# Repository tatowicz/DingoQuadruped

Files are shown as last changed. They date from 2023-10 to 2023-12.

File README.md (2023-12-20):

# Dingo Quadruped

<p align="center">
    
</p>

## Overview
This repository hosts the code for the Dingo Quadruped, a robot designed to be low-cost but capable of conducting research and being extensively modified with additional actuators and sensors. CAD for the Dingo can be found [here](https://grabcad.com/library/dingo-robot-quadruped-2). A full Bill of materials for purchasable components can be found within this repo.

This code is based on the [Stanford Pupper](https://github.com/stanfordroboticsclub/StanfordQuadruped) and [notspot](https://github.com/lnotspotl/notspot_sim_py) codebases, with extensive modifications, including integration into ROS 1 Noetic.

The repository includes a driver node, dingo_driver.py, which should be used anytime the code is run. This file enables joystick control of the Dingo, and allows joint and/or task space commands generated by any other code to be passed through the driver via the appropriate ROS command topics. The joystick can also be toggled on and off to override commands received via ROS command topics

The repo also includes a gazebo simulation of the Dingo, based on URDF file and meshes which are also provide.

## How Dingo_driver Works
The following flow diagram shows a simplified overview of how a joystick command is handled by the driver to affect joint movements:
<p align="center">
    
</p>

## Project Structure
```.
├── assets                                    Images used in the readme file
├── dingo_nano                                Code for the Arduino Nano V3 to read sensor data and send it to the Raspberry Pi
└── dingo_ws                                  ROS workspace containing all required packages
   └── src
     ├── dingo                                Package containing node and launch files for running the robot
     ├── dingo_control                        Package containing all files related to control, including kinematics and default trot controller
     ├── dingo_description                    Package containing simulation files (URDF file and meshes)
     ├── dingo_gazebo                         Package containing gazebo files
     ├── dingo_hardware_interfacing
     |  ├── dingo_input_interfacing           Package containing files for receiving and interpreting commands (From a joystick or keyboard)
     |  ├── dingo_peripheral_interfacing      Package containing files for interfacing with the Arduino Nano, LCD screen and IMU
     |  └── dingo_servo_interfacing           Package containing the hardware interface for sending joint angles to the servo motors
     └── dingo_utilities                      Package containing useful utilities
```

## Installation of Code
### Natively
- Install Ubuntu 20.04
- Install [ros-noetic](http://wiki.ros.org/noetic/Installation/Ubuntu)
- Install git via `sudo apt-get install git`
- Create a new folder in your home folder: `mkdir ~/any_folder_name`
- Change directory to the new folder just created: `cd ~/any_folder_name`
- Clone this repository into the folder using git: `git clone ...`
- Move into the dingo_ws folder: `cd /dingo_ws`
- Initialise rosdep: `sudo rosdep init`
- Fetch dependencies with rosdep: `rosdep update`
- Build the workspace: `catkin build`
- Source the workspace: `source devel/setup.bash`
- (Optional) Add a line to .bashrc to automatically source the workspace: `echo "source ~/any_folder_name/DingoQuadruped/dingo_ws/devel/setup.bash" >> ~/.bashrc`, `source ~/.bashrc`

### Additional Installation Steps
#### Setting necessary permissions for ROS
To run ROS as non-root, must set permissions correctly via udev for several /dev files.
- Add the following to /etc/udev/rules.d/99-ROS.rules
```.   
       KERNEL=="ttyS0", OWNER="root", GROUP="ros", MODE="0660"
       KERNEL=="spi", OWNER="root", GROUP="ros", MODE="0660"
       KERNEL=="i2c", OWNER="root", GROUP="ros", MODE="0660"
       KERNEL=="gpiomem", OWNER="root", GROUP="ros", MODE="0660"
       KERNEL=="mem", OWNER="root", GROUP="ros", MODE="0660"
```
- Add new group to user account: `sudo groupadd ros && sudo adduser <username> ros`
- Reload udev rules: `sudo udevadm control --reload-rules && sudo udevadm trigger`

#### Setting up Serial Comms
These steps will be required to get serial comms working between the Pi and Nano.
- Run the following to install ROS serial
    - `sudo apt-get update`
    - `sudo apt-get install ros-noetic-rosserial-python ros-noetic-rosserial-arduino`
- See above for udev changess needed for ttyS0 
- The Ubuntu serial console must be disabled or it will conflict with serial comms.
    - `sudo systemctl disable serial-getty@ttyS0.service --now`
    - `sudo systemctl stop serial-getty@ttyS0.service`
    - `sudo systemctl mask serial-getty@ttyS0.service`

#### Bluetooth Setup
For getting bluetooth controller working (for instance PS4 controller)
- More info here: https://www.makeuseof.com/manage-bluetooth-linux-with-bluetoothctl/
- Install bluetooth: 
    - `sudo apt-get install bluetooth bluez bluez-tools`
    - `sudo apt-get install pi-bluetooth`
- To pair and connect a controller:
    - `bluetoothctl scan on`
    - `bluetoothctl pair AA:BB:CC:11:22:33` (example device)
    - `bluetoothctl connect AA:BB:CC:11:22:33`
    - `bluetoothctl trust AA:BB:CC:11:22:33`
- To test the controller
    - `jstest /dev/input/js0`

At this stage, the controller will only connect if you run `bluetoothctl` in the terminal, and then press the pair button on the controller. To bypass the step of running `bluetoothctl`, do the following:
- Create a shell script called connect_controller.sh (Make a note of where you create it) with the following contents:
```.
#!/bin/bash

# Replace 'XX:XX:XX:XX:XX:XX' with your controller's MAC address
controller_mac="XX:XX:XX:XX:XX:XX"

# Use bluetoothctl to connect the controller
bluetoothctl <<EOF
connect $controller_mac
exit
EOF`
```
- Make it executable by running `chmod +x connect_controller.sh`
- Create a UDEV rule to run this script every time the controller attempts to pair: `SUBSYSTEM=="bluetooth", KERNEL=="hci0", ACTION=="add", ENV{DEVTYPE}=="adapter", TAG+="systemd", SYMLINK+="bluetooth", RUN+="/bin/sleep 10", RUN+="/path/to/connect_controller.sh"`
- reload the UDEV rules: `sudo udevadm control --reload`
The controller should now autopair every time the pair button is pressed, without needing to do anything on the Pi

#### Wifi Setup
To get WiFi working
- Edit the file /etc/netplan/50-cloud-init.yaml 
- Add the following to the bottom of the file
```.   
    wifis:
        wlan0:
            optional: true
            dhcp4: true
            access-points:
                "<wifi SSID>":
                    password: "<wifi password>"
```  

If getting an error with "rounded_rectangle", need to install later version of Pillow.
- Upgrade pillow with `pip3 install --upgrade Pillow`

#### LCD Node Additional Setup
The LCD node has been created following the waveshare tutorial here: https://www.waveshare.com/wiki/1.47inch_LCD_Module. Apart from installing the libraries listed there, the fonts also need to be moved into the ubuntu fonts folder to be used by executing the following lines:
- `cd ~`
- `sudo apt-get install unzip -y`
- `sudo wget https://files.waveshare.com/upload/8/8d/LCD_Module_RPI_code.zip`
- `sudo unzip ./LCD_Module_RPI_code.zip`
- `cd python/Font`
- `sudo mv Font00.ttf /usr/share/fonts/truetype/Font00.ttf`
- `sudo mv Font01.ttf /usr/share/fonts/truetype/Font01.ttf`
- `sudo mv Font02.ttf /usr/share/fonts/truetype/Font02.ttf`

#### SD Card Backup
It's a good idea to backup the sdcard every so often. Here is how to do that on linux.
- Take out the sdcard from the Raspberry Pi and mount it into another linux system.
- Run these commands to backup/restore. Replace source/destination appropriately.
    - Backup to file: `sudo dd if=/dev/sdb of=~/dingo_backup.img bs=4M status=progress`
    - Restore back to sdcard: `sudo dd if=dingo_backup of=/dev/sdb bs=4M status=progress`

#### Servo Calibration
Help with getting the servos calibrated
 - View the CalibrateServos script itself for additional instructions on dialing in servos.
 - (dingo_hardware_interfacing/dingo_servo_interfacing/src/dingo_servo_interfacing/CalibrateServos.py)
 - Example commands:
    - `rosrun dingo_servo_interfacing CalibrateServos all cal` (move all servos to calibration position)
    - `rosrun dingo_servo_interfacing CalibrateServos fr high` (move front right servo to high position)

### Docker Container
The files inside the base directory enable a docker container to be built and the code to inspected and debugged in visual studio code. This is mostly for debugging purposes, and is best for an external device debugging or adding to the code, rather than being used on the quadruped itself. Note: These instructions assume a linux OS.
#### Preparing vscode
- Install [docker](https://docs.docker.com/engine/install/ubuntu/)
- Install [vscode](https://code.visualstudio.com/docs/setup/linux)
- Open vscode and add the following extensions: [C/C++ Extension Pack](https://marketplace.visualstudio.com/items?itemName=ms-vscode.cpptools-extension-pack), [Docker](https://marketplace.visualstudio.com/items?itemName=ms-azuretools.vscode-docker), [Dev Containers](https://marketplace.visualstudio.com/items?itemName=ms-vscode-remote.remote-containers), [ROS](https://marketplace.visualstudio.com/items?itemName=ms-iot.vscode-ros)
- close vscode once extensions are installed

#### Building and/or opening the container in vscode
- In terminal, open the base folder containing the dingo quadruped code: `cd ~/any_folder_name/DingoQuadruped`
- run `code .` to open the dingo quadruped base folder in vscode
- A prompt will appear saying either to build the container or run it, click "build" or "run"
- Wait for the container to be built and initialised
- (First time only) Once the container is built, Check that "ROS1.noetic" appears in the bottom left to indicate that the ros extension has correctly detected the ros version inside the container. If it does not appear, follow [these steps](https://youtu.be/JbBMF1aot5k?t=356)

## Running the code
### Dingo_Driver
The Dingo_Driver should be started before any other code is launched on the Dingo. It starts joystick control of the robot and allows joint and task space commands to be received from other code or controllers via command ROS topics, as long as joystick control is disabled. If enabled, joystick control will override any commands sent through the command topics. To launch it, run the following line:
`roslaunch dingo dingo.launch`

Arguments are:
- is_physical (0/1): Is the code being run on the Dingo itself? Default: "1" (Yes)
- is_sim (0/1): Should the code publish joint values to the simulator? Default: "0" (No)
- use_joystick (0/1): Is a joystick being used for control? Default: "1" (Yes)
- use_keyboard (0/1): Is the keyboard being used for control? Default: "0" (No)
- (currently not used) serial_port (name of port): The serial port that the nano is connected to. Default: "/dev/ttyS0"
- use_imu (0/1): Should IMU data be used to correct the robots joint angles? Default: "0" (No)

With no arguments specified, it will assume a joystick controller is used for control and it will launch the hardware interface with IMU feedback disabled. No joint data will be published for Gazebo to use to simulate the robot.

As an example of how the arguments can be used, if the code is to be run purely in simulation with joystick control, you would launch the driver with the following arguments: 
`roslaunch dingo dingo.launch is_physical:=0 is_sim:=1`

### Dingo Joystick Controls
<p align="center">
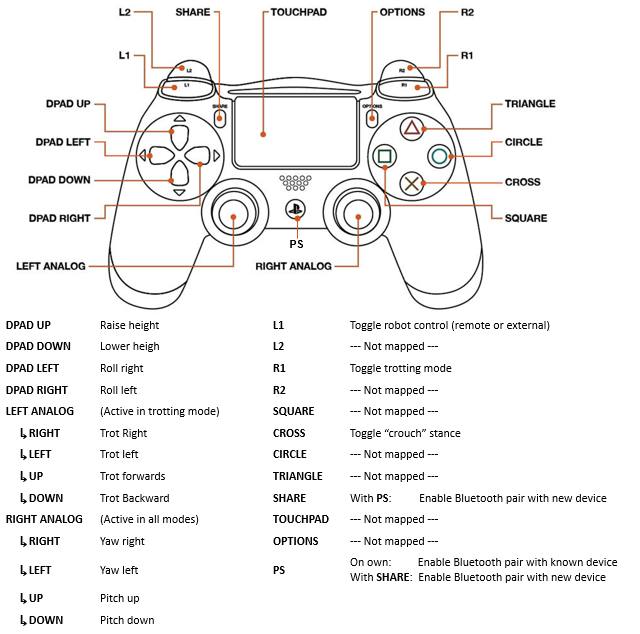
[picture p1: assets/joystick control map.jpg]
    
</p>

The diagram above shows the mapping of joystick commands for the Dingo. These instructions are based on a PS4 type controller. An alternative, more general description of joystick commands is below:

The Dingo has two main states: Rest and Trot. 
- While in the TROT state: Left stick controls the robot's movement. Right stick controls the robot's tilt and turning.
- While in the REST state: Left stick is disabled. Right stick controls the robot's gaze while staying in place.

Buttons:
- Joystick Control Toggle (L1 Button): Pause/Resume control from the joystick.
- Gait Toggle (R1 Button): Toggles between trotting and resting modes.
- Hop Request (X button): Perform a hop (Currently not implemented).

Movement: (Speed proportional to how far stick is moved)
- Left Stick (Horizontal): Pushing left or right strafes the robot in that direction.
- Left Stick (Vertical): Push up to move forward, down to move backward.

Gaze:
- Right Stick (Horizontal): Pushing left or right turns the robot in that direction.
- Right Stick (Vertical): Push up to raise front of robot, down to raise back of robot.

Orientation:
- D-pad (Vertical): Pressing up or down adjusts the height of the robot.
- D-pad (Horizontal): Pressing left or right tilts the robot in that direction.

### Launching the gazebo simulation
Make sure dingo_driver is running first, then:
`roslaunch dingo_gazebo simulation.launch`

### Extra Notes on Running in the Docker Container
#### Using the ros workspace in vscode
The ROS extension provides options to roslaunch and rosrun files inside vscode via the inbuilt terminal without needing to use the native linux terminal. The commands to do so are the same as natively. 

To start/stop a roscore daemon inside vscode, you can type `ctrl+shift+P` in vscode, and then type `ROS: Start` to start and `ROS: Stop` to stop the roscore daemon.

To build or rebuild the ros workspace, type `ctrl+shift+B`. If this does not work, you may need to edit the tasks.json file which tells vscode how to build the container. Ensure that the catkin build task defined in tasks.json includes the option `-DCMAKE_BUILD_TYPE=Debug`, as without this the vscode debugger will not work correctly.

An important note, as the entire ros workspace is volume mounted, files can be edited inside the container and reflected in your native linux filesystem and vice versa. This means the code can be changed and debugged in the vscode container but run natively, with all changes being reflected. 

#### Debugging with vscode
The ROS extension has two options to enable debugging. The first is to attach to a running node which you start via the terminal with `rosrun package_name node_name`. The second is to debug from a launch file, where you use the debugger menu in vscode to launch a launch file and then set waypoints in any nodes which the launch file starts. To set this up, please watch [this video](https://youtu.be/N2vqBvPQdhE?list=PL2dJBq8ig-vihvDVw-D5zAYOArTMIX0FA)

If the debugger is not stopping at breakpoints, you may need to edit the tasks.json file which tells vscode how to build the container. Ensure that the catkin build task defined in tasks.json includes the option `-DCMAKE_BUILD_TYPE=Debug`.

#### Updates

- Added CAD files to lfs exported in .f3d format (fusion 360)
- Added power PCB files in fusion360 format, re-draw and layout
- Moved away from fork, since it doesn't support LFS

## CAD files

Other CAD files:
CAD/Dingo Quadruped v7.f3d
CAD/PowerPCB v7.f3d
PCB/ADS1115 v2.f3z
PCB/BNO055 v2.f3z
PCB/PowerPCB v33.f3z

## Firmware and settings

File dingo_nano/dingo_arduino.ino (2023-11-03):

#include <ros.h>
#include <std_msgs/Bool.h>
#include <std_msgs/Float32.h>
#include <Dingo_Peripheral_Interfacing/ElectricalMeasurements.h>
#include <avr/sleep.h>

ros::NodeHandle_<ArduinoHardware, 5, 5, 128, 256> arduino_nano_node; //(max) 5 publishers, 2 subscribers, 64 byte input buffer, 256 byte output buffer. Default is 25,25,512,512

//Declare global message variables for storing data to publish
std_msgs::Bool emergency_stop_msg;
dingo_peripheral_interfacing::ElectricalMeasurements electrical_measurement_msg;

//Declare publishers for data to be published on topics
ros::Publisher emergency_stop_status_publisher("emergency_stop_status", &emergency_stop_msg);
ros::Publisher electrical_measurement_publisher("electrical_measurements", &electrical_measurement_msg);

//Declare constants
const int publish_interval = 1; // publish voltage every 1 second

const int number_stored_battery_voltage_measurements = 30; // number of battery voltage values to average against
const int number_stored_buck_voltage_measurements = 5; // number of buck voltage values to average against

const float battery_R1 = 45.5; // resistor value between the pos battery terminal and nano pin
const float battery_R2 = 9.87; // resistor value between the neg battery terminal and nano pin
const float battery_minimum_voltage = 14.0;
const float battery_reference_voltage = 16.8;
const float battery_diode_drop = 0.2;
const float battery_fine_tuning = 1.067;

const float servobuck_R1 = 400.0; // resistor value between the pos buck terminal and nano pin
const float servobuck_R2 = 400.0; // resistor value between the neg buck terminal and nano pin
const float servobuck_minimum_voltage = 6.0;
const float servobuck_reference_voltage = 7.0;
const float servobuck_fine_tuning = 1.055;

// Declare global variables
float battery_buck_voltage_array[number_stored_battery_voltage_measurements] = {0.0};
float servobuck_voltage_array[number_stored_buck_voltage_measurements] = {0.0};

float battery_filtered_voltage = 0.0;
float servobuck_filtered_voltage = 0.0;

int buck_voltage_array_index = 0;
int number_of_low_battery_detections = 0;
int number_of_low_buck_voltage_detections = 0;
bool currently_estopped = 0;

void setup()
{
  // Wait 15 seconds before checking starting serial.
  // This avoids Raspberry Pi detecting serial console keystrokes and stopping autoboot.
  delay(15000); 

  // This function is required by arduino standards, and is run once on startup to initialise ros, publishers, subscribers and array initial values
  Serial.begin(57600);

  while (!Serial.available()) {
    // Wait 1 second before checking again
    delay(1000); 
  }

  arduino_nano_node.getHardware()->setBaud(57600);
  // Initialise ros node, and advertise publishers
  arduino_nano_node.initNode();
  arduino_nano_node.advertise(emergency_stop_status_publisher);
  arduino_nano_node.advertise(electrical_measurement_publisher);

  // Multiple spins and delays to allow time for publishers to be properly setup before data is collected and transmitted
  arduino_nano_node.spinOnce(); delay(1000);
  arduino_nano_node.spinOnce(); delay(1000);
  arduino_nano_node.spinOnce(); delay(1000);
}

void shutdown()
{
  // Shuts the arduino down if the voltage level is too low

  // Log the shutdown in ROS logs
  arduino_nano_node.logwarn("BATTERY VOLTAGE TOO LOW: NANO POWERING DOWN");
  delay(1000);

  // Put arduino to sleep, which is as close to shutdown as possible
  set_sleep_mode(SLEEP_MODE_PWR_DOWN);  
  sleep_enable();
  sleep_cpu ();             
}

void checkBatteryVoltageLevel()
{
  // Retrieves the current voltage of the battery. Uses this and previous stored voltages to calculate the average voltage of the battery, then publishes to pi
  // This function also checks that the battery voltage is above the minimum, and will call the shutdown code if the voltage is too low
  
  // Get the voltage at the analogue port of the arduino
  int sensorValue = analogRead(A0);
  
  // Convert this voltage into the actual battery voltage and store into an array of voltage readings
  float pin_voltage = sensorValue * (5.0 / 1023.0);
  float current_voltage = pin_voltage * ((battery_R1+battery_R2)/battery_R2) + battery_diode_drop;

  // Fine tuning adjustment
  current_voltage = current_voltage * battery_fine_tuning;

  float battery_average_voltage = calculateAverageVoltage(
    current_voltage, battery_buck_voltage_array, number_stored_battery_voltage_measurements, battery_filtered_voltage, battery_reference_voltage);

  // Serial.println(String(pin_voltage));
  // Serial.println(String(battery_average_voltage));

  // Write the current average voltage to the publisher message
  electrical_measurement_msg.battery_voltage_level = battery_average_voltage;

  // Check whether the voltage is below the minimum. If so, increment the number of low battery detections. If too many have occured, order shutdown of nano
  if (battery_average_voltage < battery_minimum_voltage)
  {
    if (number_of_low_battery_detections > 30)
    {
      shutdown(); // TODO: ROS topic to shutdown pi as well
    }
    else
    {
      number_of_low_battery_detections++;
    }
    
  } // Decrement number of low battery detections if it was above zero and the battery voltage is above the minimum acceptable
  else if (battery_average_voltage > battery_minimum_voltage && number_of_low_battery_detections > 0)
  {
    number_of_low_battery_detections = number_of_low_battery_detections - 1;
  }
}

void checkBuckVoltageLevel()
{
  // Retrieves the current voltage of the buck converter output. Uses this and previous voltages to calculate the average voltage of the buck converter output, then publishes to pi
  // This function also checks whether the buck converter has dropped to zero. If it has for long enough, the e-stop must have been pressed to shut down power to the buck and servos, so publish this
  // Also checks when the voltage increases again, indicating that the e-stop has been released, and publishes this as well

  // Get the voltage at the analogue port of the arduino
  int sensorValue = analogRead(A1);

  // Convert this voltage into the actual buck converter output voltage and store into an array of voltage readings
  float pin_voltage = sensorValue * (5.0 / 1023.0);
  float current_voltage = pin_voltage * ((servobuck_R1+servobuck_R2)/servobuck_R2);

  // Fine tuning adjustment
  current_voltage = current_voltage * servobuck_fine_tuning;

  float servobuck_average_voltage = calculateAverageVoltage(
    current_voltage, servobuck_voltage_array, number_stored_buck_voltage_measurements, servobuck_filtered_voltage, servobuck_reference_voltage);

  // Serial.println(String(pin_voltage));
  // Serial.println(String(servobuck_average_voltage));

  // Write the current average voltage to the publisher message
  electrical_measurement_msg.servo_buck_voltage_level = servobuck_average_voltage;

  // Check whether the buck converter voltage has dropped to 0 (or near 0). If it has, send message that the e-stop has been pressed
  if (servobuck_average_voltage < servobuck_minimum_voltage)
  {
    if (number_of_low_buck_voltage_detections < 3)
    {
      number_of_low_buck_voltage_detections = number_of_low_buck_voltage_detections + 1;
    }
    else if (currently_estopped == 0)
    {
      currently_estopped = 1;
      emergency_stop_msg.data = 1;
      emergency_stop_status_publisher.publish(&emergency_stop_msg);

    }
  } // If buck converter voltage has recently increased from 0, send message that e-stop has been released
  else if (servobuck_average_voltage > servobuck_minimum_voltage)
  {
    if (number_of_low_buck_voltage_detections > 0)
    {
      number_of_low_buck_voltage_detections = number_of_low_buck_voltage_detections - 1;
    }
    else if (currently_estopped == 1)
    {
      currently_estopped = 0;
      emergency_stop_msg.data = 0;
      emergency_stop_status_publisher.publish(&emergency_stop_msg);
    }
  }

  // Increment the index for where electrical measurements are kept inside respective array
  if (buck_voltage_array_index == number_stored_buck_voltage_measurements - 1)
  {
    buck_voltage_array_index = 0;
  }
  else
  {
    buck_voltage_array_index++;
  }
}

void loop()
{
  // This function is required by arduino and runs constantly in a loop while it is powered
  // It calls functions to measure sensor data on every loop, publishing this data to topics. Also spins topics to clear buffers

  static unsigned long lastPublishMillis = 0;  // last time the message was published
  unsigned long currentMillis = millis();  // current time
    
  // Check voltage of battery and buck converter output
  checkBatteryVoltageLevel();
  checkBuckVoltageLevel();

  
  // Publish electrical measurements to the electrical measurement topic
  if (currentMillis - lastPublishMillis >= publish_interval * 1000) {
    electrical_measurement_publisher.publish(&electrical_measurement_msg);
    lastPublishMillis = currentMillis;
  }

  // Spin nodes
  arduino_nano_node.spinOnce();

  // Runs every 100ms at the moment.
  delay(100); //NOTE: ros-serial does not have an equivalent ros sleep function, so need to use native delay. Not a major issue for us.
  
}

float calculateAverageVoltage(float last_voltage, float voltage_array[], int voltage_array_size, float& filtered_voltage, float reference_voltage) {
    float sum_of_voltages = 0.0;

    // Shift voltages in array
    for(int i = 0; i < voltage_array_size-1; i++) {
        voltage_array[i] = voltage_array[i + 1];
    }
    // Assign the last voltage reading to the last element
    voltage_array[voltage_array_size-1] = last_voltage;

    // Calculate the current average of all the voltages in the array
    for (int i = 0; i < voltage_array_size; i++) {
        sum_of_voltages += voltage_array[i];
    }
    
    float average_voltage = (sum_of_voltages / voltage_array_size);
    
    // The filtered voltage should just be set to reference voltage if averaging array is not fully populated
    // And battery voltage should only update if current average is lower than the previous average.
    if (reference_voltage == servobuck_reference_voltage)
    {
      filtered_voltage = average_voltage;   
    } else {
      if (find_min(voltage_array, voltage_array_size) == 0) {
          filtered_voltage = reference_voltage;
      } else if (average_voltage < filtered_voltage) {
          filtered_voltage = average_voltage;
      } 
    } 

    return filtered_voltage;
}

int find_min(float arr[], int n) {
    int min_val = arr[0];
    for(int i = 1; i < n; i++) {
        if(arr[i] < min_val) {
            min_val = arr[i];
        }
    }
    return min_val;
}

int find_max(float arr[], int n) {
    int max_val = arr[0];
    for(int i = 1; i < n; i++) {
        if(arr[i] > max_val) {
            max_val = arr[i];
        }
    }
    return max_val;
}

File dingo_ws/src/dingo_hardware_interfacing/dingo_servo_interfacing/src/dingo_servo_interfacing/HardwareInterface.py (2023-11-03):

#!/usr/bin/env python3
from adafruit_servokit import ServoKit
import numpy as np
import math as m
import rospy

class HardwareInterface():
    def __init__(self,link):
        self.pwm_max = 2400
        self.pwm_min = 370
        self.link = link
        self.servo_angles = np.zeros((3,4))
        self.kit = ServoKit(channels=16) #Defininng a new set of servos uising the Adafruit ServoKit LIbrary
        
        """ SERVO INDICES, CALIBRATION MULTIPLIERS AND OFFSETS
            #   ROW:    which joint of leg to control 0:hip, 1: upper leg, 2: lower leg
            #   COLUMN: which leg to control. 0: front-right, 1: front-left, 2: back-right, 3: back-left.

                #               0                  1                2               3
                #  0 [[front_right_hip  , front_left_hip  , back_right_hip  , back_left_hip  ]
                #  1  [front_right_upper, front_left_upper, back_right_upper, back_left_upper]
                #  2  [front_right_lower, front_left_lower, back_right_lower, back_left_lower]] 

           'pins' define the physical pin of the servos on the servoboard """
        self.pins = np.array([[14,10,2,6], 
                              [13,9,1,5], 
                              [12,8,0,4]])

        """ 'servo_multipliers' and 'complementary_angle' both work to flip some angles, x, to (180-x) so that movement on each leg is consistent despite
            physical motor oritentation changes """
        self.servo_multipliers = np.array(
                            [[-1, 1, 1, -1], 
                            [1, -1, 1, -1], 
                            [1, -1, 1, -1]])
        self.complementary_angle = np.array(
                            [[180, 0, 0, 180], 
                            [0, 180, 0, 180], 
                            [0, 180, 0, 180]])

        """ 'physical_calibration_offsets' are the angle required for the servo to be at their 'zero'locations. These zero locations
            are NOT the angles deifned in the IK, but rather locations that allow practical usage of the servo's 180 degree range of motion. 

            - Offsets for HIP servos allign the hip so that the leg is perfectly vertical at an input of zero degrees, direct from the IK.
            - Offsets for UPPER leg servos map allign the servo so that it is horizontal toward the back of the robot at an input of zero degrees, direct from the IK. 
            - Offsets for LOWER leg servos map allign the servo so that it is vertically down at zero degrees. Note that IK requires a transformation of
                angle_sent_to_servo = (180-angle_from_IK) + 90 degrees to map to this physcial servo location.  """
        self.physical_calibration_offsets = np.array(
                    [[75, 130, 113, 73],
                    [29, 13, 33, 15],
                    [26, 12, 30, 4]])
        #applying calibration values to all servos
        self.create()

    def create(self):
        for i in range(16):
            self.kit.servo[i].actuation_range = 180
            self.kit.servo[i].set_pulse_width_range(self.pwm_min, self.pwm_max)

    def set_actuator_postions(self, joint_angles):
        """Converts all angles found via inverse kinematics to the angles needed at the servo by applying multipliers
        and offsets for complimentary angles.
        It then outputs the correct angle to the servo via the adafruit servokit library. 

        Parameters
        ----------
        joint_angles : 3x4 numpy array of float angles (radians)
        """
        # Limit angles ot physical possiblity
        possible_joint_angles = impose_physical_limits(joint_angles)
        
        #Convert to servo angles
        self.joint_angles_to_servo_angles(possible_joint_angles)

        # print('Final angles for actuation: ',self.servo_angles)    
        for leg_index in range(4):
            for axis_index in range(3):
                try:
                    self.kit.servo[self.pins[axis_index,leg_index]].angle = self.servo_angles[axis_index,leg_index]
                except:
                    rospy.logwarn("Warning - I2C IO error")
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

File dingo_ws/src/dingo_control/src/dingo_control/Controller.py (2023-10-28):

from dingo_control.Gaits import GaitController
from dingo_control.StanceController import StanceController
from dingo_control.SwingLegController import SwingController
from dingo_utilities.Utilities import clipped_first_order_filter
from dingo_control.State import BehaviorState, State
from dingo_control.msg import TaskSpace, JointSpace, Angle

import numpy as np
from transforms3d.euler import euler2mat, quat2euler
from transforms3d.quaternions import qconjugate, quat2axangle
from transforms3d.axangles import axangle2mat
import rospy
from geometry_msgs.msg import Point
from std_msgs.msg import Header
from math import degrees


class Controller:
    """Controller and planner object
    """

    def __init__(
        self,
        config,
        inverse_kinematics,
    ):
        self.config = config

                ################# ROS PUBLISHER FOR TASK SPACE GOALS ##############
        self.task_space_pub = rospy.Publisher('task_space_goals', TaskSpace, queue_size=10)
        self.joint_space_pub = rospy.Publisher('joint_space_goals', JointSpace, queue_size=10)

        self.smoothed_yaw = 0.0  # for REST mode only
        self.inverse_kinematics = inverse_kinematics

        self.contact_modes = np.zeros(4)
        self.gait_controller = GaitController(self.config)
        self.swing_controller = SwingController(self.config)
        self.stance_controller = StanceController(self.config)

        self.hop_transition_mapping = {BehaviorState.REST: BehaviorState.HOP, BehaviorState.HOP: BehaviorState.FINISHHOP, BehaviorState.FINISHHOP: BehaviorState.REST, BehaviorState.TROT: BehaviorState.HOP}
        self.trot_transition_mapping = {BehaviorState.REST: BehaviorState.TROT, BehaviorState.TROT: BehaviorState.REST, BehaviorState.HOP: BehaviorState.TROT, BehaviorState.FINISHHOP: BehaviorState.TROT}
        self.activate_transition_mapping = {BehaviorState.DEACTIVATED: BehaviorState.REST, BehaviorState.REST: BehaviorState.DEACTIVATED}


    def step_gait(self, state, command):
        """Calculate the desired foot locations for the next timestep

        Returns
        -------
        Numpy array (3, 4)
            Matrix of new foot locations.
        """
        contact_modes = self.gait_controller.contacts(state.ticks)
        new_foot_locations = np.zeros((3, 4))
        for leg_index in range(4):
            contact_mode = contact_modes[leg_index]
            foot_location = state.foot_locations[:, leg_index]
            if contact_mode == 1:
                new_location = self.stance_controller.next_foot_location(leg_index, state, command)
            else:
                swing_proportion = (
                    self.gait_controller.subphase_ticks(state.ticks) / self.config.swing_ticks
                )
                new_location = self.swing_controller.next_foot_location(
                    swing_proportion,
                    leg_index,
                    state,
                    command
                )
            new_foot_locations[:, leg_index] = new_location
        return new_foot_locations, contact_modes


    def publish_task_space_command(self, rotated_foot_locations):

        task_space_message = TaskSpace()
        task_space_message.FR_foot = Point(rotated_foot_locations[0, 0] - self.config.LEG_ORIGINS[0, 0], rotated_foot_locations[1, 0] - self.config.LEG_ORIGINS[1, 0], rotated_foot_locations[2, 0] - self.config.LEG_ORIGINS[2, 0])
        task_space_message.FL_foot = Point(rotated_foot_locations[0, 1] - self.config.LEG_ORIGINS[0, 1], rotated_foot_locations[1, 1] - self.config.LEG_ORIGINS[1, 1], rotated_foot_locations[2, 1] - self.config.LEG_ORIGINS[2, 1])
        task_space_message.RR_foot = Point(rotated_foot_locations[0, 2] - self.config.LEG_ORIGINS[0, 2], rotated_foot_locations[1, 2] - self.config.LEG_ORIGINS[1, 2], rotated_foot_locations[2, 2] - self.config.LEG_ORIGINS[2, 2])
        task_space_message.RL_foot = Point(rotated_foot_locations[0, 3] - self.config.LEG_ORIGINS[0, 3], rotated_foot_locations[1, 3] - self.config.LEG_ORIGINS[1, 3], rotated_foot_locations[2, 3] - self.config.LEG_ORIGINS[2, 3])
        task_space_message.header = Header(stamp = rospy.Time.now())
        self.task_space_pub.publish(task_space_message)

    def publish_joint_space_command(self, angle_matrix):

        joint_space_message = JointSpace()
        joint_space_message.FR_foot = Angle(degrees(angle_matrix[0, 0]), degrees(angle_matrix[1, 0]), degrees(angle_matrix[2, 0]))
        joint_space_message.FL_foot = Angle(degrees(angle_matrix[0, 1]), degrees(angle_matrix[1, 1]), degrees(angle_matrix[2, 1]))
        joint_space_message.RR_foot = Angle(degrees(angle_matrix[0, 2]), degrees(angle_matrix[1, 2]), degrees(angle_matrix[2, 2]))
        joint_space_message.RL_foot = Angle(degrees(angle_matrix[0, 3]), degrees(angle_matrix[1, 3]), degrees(angle_matrix[2, 3]))
        joint_space_message.header = Header(stamp = rospy.Time.now())
        self.joint_space_pub.publish(joint_space_message)
    

    def run(self, state, command):
        """Steps the controller forward one timestep

        Parameters
        ----------
        controller : Controller
            Robot controller object.
        """

        previous_state = state.behavior_state

        ########## Update operating state based on command ######
        if command.joystick_control_event:
            state.behavior_state = self.activate_transition_mapping[state.behavior_state]
        elif command.trot_event:
            state.behavior_state = self.trot_transition_mapping[state.behavior_state]
        elif command.hop_event:
            state.behavior_state = self.hop_transition_mapping[state.behavior_state]

        if previous_state != state.behavior_state:
            rospy.loginfo("State changed from %s to %s", str(previous_state), str(state.behavior_state))

        if state.behavior_state == BehaviorState.TROT:
            state.foot_locations, contact_modes = self.step_gait(
                state,
                command,
            )

            # Apply the desired body rotation
            rotated_foot_locations = (
                euler2mat(
                    command.roll, command.pitch, 0.0
                )
                @ state.foot_locations
            )

            # Construct foot rotation matrix to compensate for body tilt
            yaw,pitch,roll = state.euler_orientation
            #print('Yaw: ',np.round(yaw),'Pitch: ',np.round(pitch),'Roll: ',np.round(roll))
            correction_factor = 0.8
            max_tilt = 0.4
            roll_compensation = correction_factor * np.clip(roll, -max_tilt, max_tilt)
            pitch_compensation = correction_factor * np.clip(pitch, -max_tilt, max_tilt)
            rmat = euler2mat(roll_compensation, pitch_compensation, 0)

            rotated_foot_locations = rmat.T @ rotated_foot_locations
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

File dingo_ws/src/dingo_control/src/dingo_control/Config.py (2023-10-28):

import numpy as np
# from dingo_servo_interfacing.ServoCalibration import MICROS_PER_RAD, NEUTRAL_ANGLE_DEGREES
from dingo_input_interfacing.HardwareConfig import PS4_COLOR, PS4_DEACTIVATED_COLOR
from enum import Enum
import math as m



class Configuration:
    def __init__(self):
        ################# CONTROLLER BASE COLOR ##############
        self.ps4_color = PS4_COLOR    
        self.ps4_deactivated_color = PS4_DEACTIVATED_COLOR    

        #################### COMMANDS ####################
        self.max_x_velocity = 1.2
        self.max_y_velocity = 0.5
        self.max_yaw_rate = 2.0
        self.max_pitch = 30.0 * np.pi / 180.0
        
        #################### MOVEMENT PARAMS ####################
        self.z_time_constant = 0.02
        self.z_speed = 0.06  # maximum speed [m/s]
        self.pitch_deadband = 0.05
        self.pitch_time_constant = 0.25
        self.max_pitch_rate = 0.3
        self.roll_speed = 0.1  # maximum roll rate [rad/s]
        self.yaw_time_constant = 0.3
        self.max_stance_yaw = 1.2
        self.max_stance_yaw_rate = 1

        #################### STANCE ####################
        self.delta_x = 0.117 #- 0.00535 #115650.00535

        #These x_shift variables will move the default foot positions of the robot 
        #Handy if the centre of mass shifts as can move the feet to compensate
        self.rear_leg_x_shift = -0.04 #In default config, the robots mass is slightly biased to the back feet, so the back feet are shifted back slightly
        self.front_leg_x_shift = 0.00

        self.delta_y = 0.1106 #0.1083
        self.default_z_ref = -0.25 #-0.16

        #################### SWING ######################
        self.z_coeffs = None
        self.z_clearance = 0.07
        self.alpha = (
            0.5  # Ratio between touchdown distance and total horizontal stance movement
        )
        self.beta = (
            0.5  # Ratio between touchdown distance and total horizontal stance movement
        )

        #################### GAIT #######################
        self.dt = 0.01
        self.num_phases = 4
        self.contact_phases = np.array(
            [[1, 1, 1, 0], [1, 0, 1, 1], [1, 0, 1, 1], [1, 1, 1, 0]]
        )
        self.overlap_time = (
            0.04  # duration of the phase where all four feet are on the ground
        )
        self.swing_time = (
            0.07  # duration of the phase when only two feet are on the ground
        )

        ######################## GEOMETRY ######################
        self.LEG_FB = 0.11165 #   front-back distance from center line to leg axis
        self.LEG_LR = 0.061  # left-right distance from center line to leg plane
        self.LEG_ORIGINS = np.array( #Origins of the initial frame from the centre of the body
            [
                [self.LEG_FB, self.LEG_FB, -self.LEG_FB, -self.LEG_FB],
                [-self.LEG_LR, self.LEG_LR, -self.LEG_LR, self.LEG_LR],
                [0, 0, 0, 0],
            ]
        )

        #Leg lengths
        self.L1 = 0.05162024721
        self.L2 = 0.130
        self.L3 = 0.13813664159
        self.phi = m.radians(73.91738698)
        
        ################### INERTIAL ####################
        self.FRAME_MASS = 0.560  # kg
        self.MODULE_MASS = 0.080  # kg
        self.LEG_MASS = 0.030  # kg
        self.MASS = self.FRAME_MASS + (self.MODULE_MASS + self.LEG_MASS) * 4

        # Compensation factor of 3 because the inertia measurement was just
        # of the carbon fiber and plastic parts of the frame and did not
        # include the hip servos and electronics
        self.FRAME_INERTIA = tuple(
            map(lambda x: 3.0 * x, (1.844e-4, 1.254e-3, 1.337e-3))
        )
        self.MODULE_INERTIA = (3.698e-5, 7.127e-6, 4.075e-5)

        leg_z = 1e-6
        leg_mass = 0.010
        leg_x = 1 / 12 * self.L2 ** 2 * leg_mass
        leg_y = leg_x
        self.LEG_INERTIA = (leg_x, leg_y, leg_z)

    @property
    def default_stance(self): #Default stance of the robot relative to the centre frame
        return np.array(
            [
                [
                    self.delta_x + self.front_leg_x_shift, #Front Right
                    self.delta_x + self.front_leg_x_shift, #Front Left
                    -self.delta_x + self.rear_leg_x_shift, #Back Right
                    -self.delta_x + self.rear_leg_x_shift, #Back Left
                ],
                [-self.delta_y, self.delta_y, -self.delta_y, self.delta_y],
                [0, 0, 0, 0],
            ]
        )

    ################## SWING ###########################
    @property
    def z_clearance(self):
        return self.__z_clearance
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

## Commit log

2023-10-12 Fixes to serial comms, Nano code refactor. LCD battery indicator now working. Updated Readme with addl info.
    [dingo_arduino.ino, dingo_lcd_interfacing.py]
2023-10-20 Updated README with joystick controls. Fixed: Leg stances while in REST state, Config.py issues.
    [CalibrateServos.py, Config.py, Controller.py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]
2023-11-02 Clean up of the arduino code. Removed including libraries inside the dingo repo. Subsequent knowledge has made us realise that these libraries clashed with each other anyway (One was installed via ar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
2023-11-03 added extra line to gitignore to ignore any changes to calibrateServos to ensure that users can keep their calibrations in a local file when pulling the repo
2023-11-03 fixed typo in include definitions for the custom electrical_measurements message
    [dingo_arduino.ino]
2023-11-03 Various small fixes, removal of some outdated lines of code
    [HardwareInterface.py, dingo_lcd_interfacing.py, imu_test.py]
2023-12-20 Add CAD files to lfs
    [Bill of Materials-Dingo_PCB.xlsx, Dingo Quadruped v7.f3d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]
2023-12-20 Add PCB files and remove meshes
    [FL_link1.STL, FL_link2.STL, FL_link3.STL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]
2023-12-21 Resize pcb to fit mount plate
    [PowerPCB v33.f3z, PowerPCB v7.f3d]
2023-12-22 Add Datasheets and schematics for IMU, ADC and servo dirver
    [ADS1115 v2.f3z, BNO055 v2.f3z, PowerPCB v31.f3z]
2023-12-26 Upload servoclick model
2023-12-27 Progress on ADC and Servo driver
